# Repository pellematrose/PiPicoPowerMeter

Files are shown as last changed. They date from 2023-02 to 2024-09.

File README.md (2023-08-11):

# PiPicoPowerMeter
Check out my project site at [hackaday.io](https://hackaday.io/project/189359-pi-pico-power-meter)

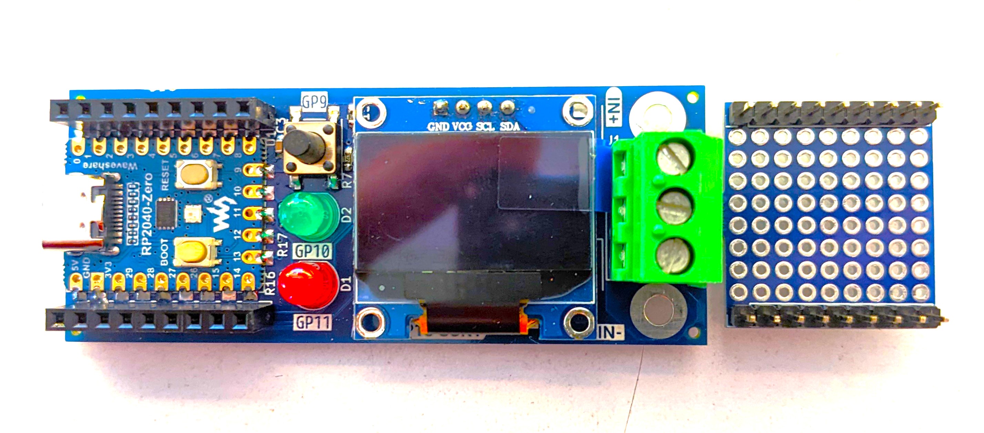
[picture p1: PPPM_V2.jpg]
PPPM_view1


Use the latest Micropython release.
Copy the content of the "RP2040 Pi Pico Code_int_log" folder to the root directory of the RP2040.

## Configuration ##
The PPPM comes pre programmed ready to go to measure up to 26V and 3.2A.

If you need other / better performance on your measured object you can change the settings in the code.
Everything is done in this function:
```python
ina.configure(SHUNT_OHMS, VBUS_RANGE_16, VSHUNT_MAX_2, BADC_12BIT, SADC_12BIT, MODE_SHUNT_BUS_C)
```
Here's how to go:
1. Estimate your maximum voltage
	1. VBUS_RANGE_32 for max. 26V
	2. VBUS_RANGE_16 for max. 16V
2. Estimate the maximum current (with 0.1Ohms shunt) and set the gain
	1. VSHUNT_MAX_1 for range +-0.04mV -> Imax = 0.4A
	2. VSHUNT_MAX_2 for range +-0.08mV -> Imax = 0.8A
	3. VSHUNT_MAX_4 for range +-0.16mV -> Imax = 1.6A
	4. VSHUNT_MAX_8 for range +-0.32mV -> Imax = 3.2A
This will change the value of the LSB and thus change the precision.
The LSB is calculated like this: $LSB = \frac{maxcurrent}{2^{15}}$
If you soldered a different shunt the max. current changes to: $I=\frac{range}{shunt}$
3. Conversion speed (the faster the less accurate) Valid for BADC (Bus voltage)and SADC (Shunt voltage)
	1. BADC_9BIT for 9bit values in 84µs
	2. BADC_10BIT for 10bit values in 148µs
	3. BADC_11BIT for 11bit values in 276µs
	4. BADC_12BIT for 12bit values in 532µs
	5. BADC_2S for 2 Samples in 1.06ms
	6. BADC_4S for 4 Samples in 2.13ms
	7. BADC_8S for 8 Samples in 4.26ms
	8. BADC_16S for 16 Samples in 8.51ms
	9. BADC_32S for 32 Samples in 17.02ms
	10. BADC_64S for 64 Samples in 34.05ms
	11. BADC_128S for 128 Samples in 68.1ms
4. Choose the mode you need
	1. MODE_POWER_DOWN compleatly off
	2. MODE_SHUNT_TRIG only shunt, triggered
	3. MODE_VOLT_TRIG  only voltage, triggered
	4. MODE_SHUNT_BUS_T shunt and voltage, triggered
	5. MODE_ADC_OFF only adc off
	6. MODE_SHUNT_C only shunt, continuous
	7. MODE_VOLT_C only voltage, continuous
	8. MODE_SHUNT_BUS_C shunt and voltage, continuous

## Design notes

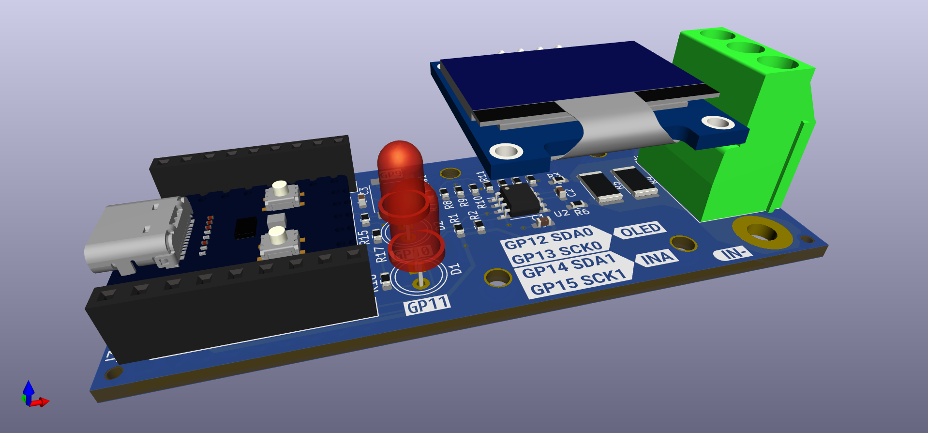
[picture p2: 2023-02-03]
PPPM_view1.png

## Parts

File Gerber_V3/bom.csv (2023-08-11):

Designator | Footprint | Quantity | Value | LCSC Part #
C1, C2 | 0603 | 2 | 100nF
C3 | 0603 | 1 | 10n
D1, D2 | LED_D5.0mm | 2 | LED
D3, D4 | D_SMB | 2 | SM6T27A
J1 | MKDS_3_3 | 1 | Conn_01x03_Female
J2, J3 | PinSocket_1x09_P2.54mm_Vertical | 2 | Conn_01x09_Female
J4, J5 | PinHeader_1x09_P2.54mm_Vertical | 2 | Conn_01x09_Female
R1, R10, R11, R12, R13, R14, R2, R7, R8, R9 | 0603 | 10 | 4k7
R15 | 0603 | 1 | 10k
R16, R17 | 0603 | 2 | 120R
R3, R6 | 0603 | 2 | 10R
R4, R5 | 2512 | 2 | 0.1R
SW1 | SW_Push_1P1T_NO_6x6mm_H9.5mm | 1 | SW_MEC_5G
U1 | RP2040-Zero_SMD | 1 | RP2040_Zero
U2 | SOIC-8_3.9x4.9mm_P1.27mm | 1 | INA219AxD
U3 | SSD1306_0.96_Oled_wo_Holes | 1 | OLED_SSD1306

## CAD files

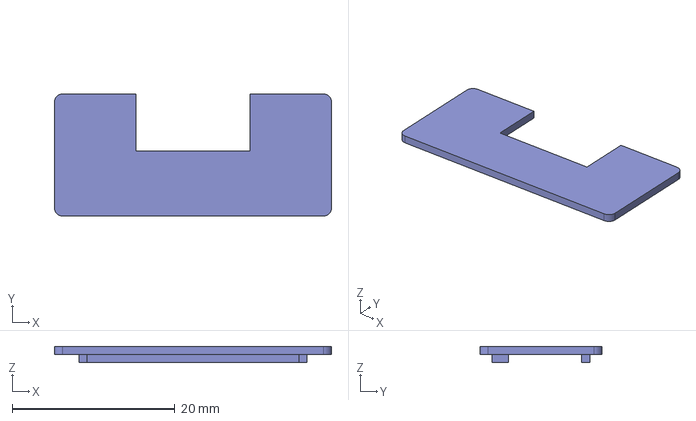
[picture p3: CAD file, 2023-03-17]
V2_Out.step
34.0 x 15.0 x 2.00 mm

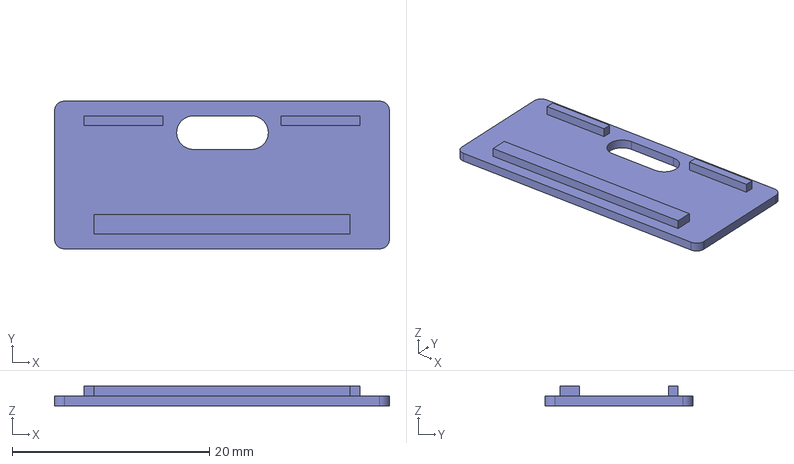
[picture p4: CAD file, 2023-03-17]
V2_USB.step
34.0 x 15.0 x 2.00 mm

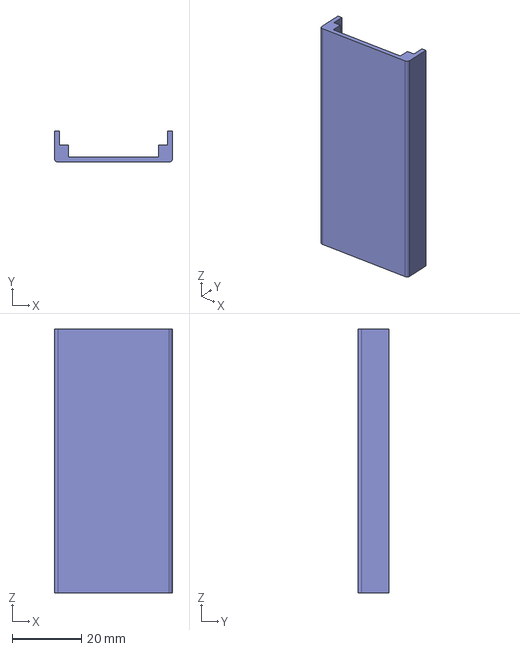
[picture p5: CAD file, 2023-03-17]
V2_Bottom.step
34.0 x 9.00 x 76.0 mm

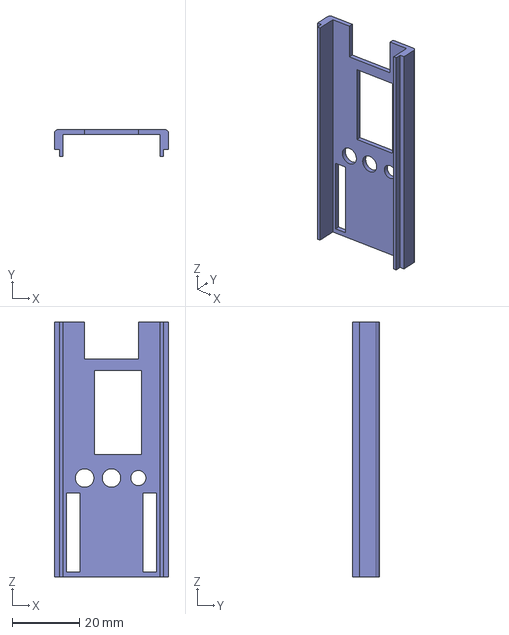
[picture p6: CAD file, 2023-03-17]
V2_Top.step
34.0 x 8.00 x 76.0 mm

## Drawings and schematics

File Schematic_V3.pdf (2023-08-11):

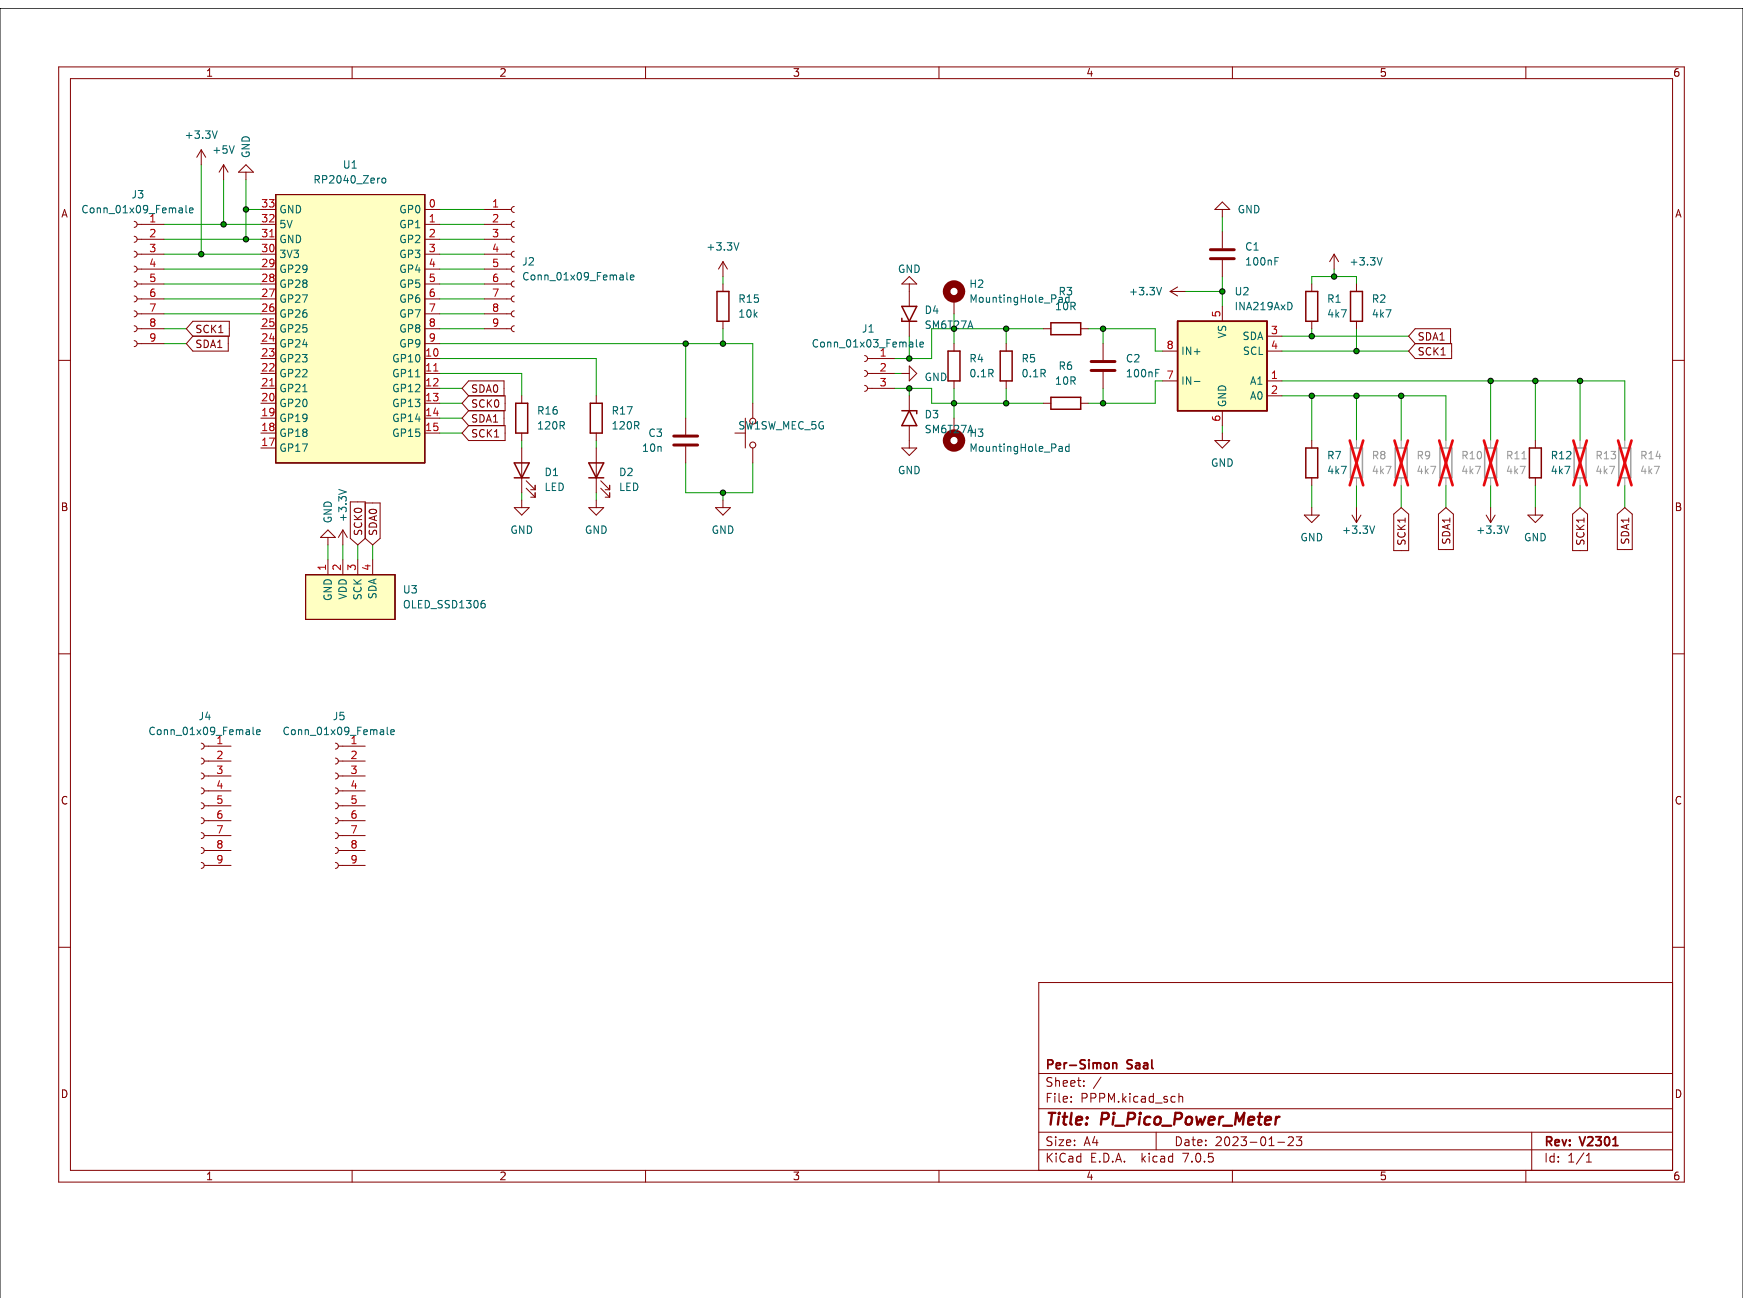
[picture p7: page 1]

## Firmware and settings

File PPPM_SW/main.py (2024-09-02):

# Inspired from
# https://www.youtube.com/watch?v=YR9v04qzJ5E
# mono_test.py Demo program for nano_gui on an SSD1306 OLED display.

# Released under the MIT License (MIT). See LICENSE.
# Copyright (c) 2018-2021 Peter Hinch

# https://learn.adafruit.com/monochrome-oled-breakouts/wiring-128x32-spi-oled-display
# https://www.proto-pic.co.uk/monochrome-128x32-oled-graphic-display.html

# V0.33 16th Jan 2021 Hardware configuration is now defined in color_setup to be
# consistent with other displays.
# V0.32 5th Nov 2020 Replace uos.urandom for minimal ports

# Last edit: 29.08.2024
# Copyright (c) 2023 Per-Simon Saal

from machine import Pin, I2C, UART
from struct import unpack
from time import sleep
import time
import math
from drivers.ina219 import ina219
import utime
from functions import format_number, show_value, multi_show_values, start_screen

from color_setup import ssd

#INA219 CONFIG
INA_ADDR = 64

VBUS_RANGE_16 = 0x00	#BRNG
VBUS_RANGE_32 = 0x01
VSHUNT_MAX_1 = 0x00		#0.040 gain
VSHUNT_MAX_2 = 0x01		#0.080
VSHUNT_MAX_4 = 0x02		#0.160
VSHUNT_MAX_8 = 0x03		#0.320

BADC_9BIT  = 0x00
BADC_10BIT = 0x01
BADC_11BIT = 0x02
BADC_12BIT = 0x03
BADC_2S = 0x08
BADC_4S = 0x0A
BADC_8S = 0x0B
BADC_16S = 0x0C
BADC_32S = 0x0D
BADC_64S = 0x0E
BADC_128S = 0x0F

SADC_9BIT  = 0x00
SADC_10BIT = 0x01
SADC_11BIT = 0x02
SADC_12BIT = 0x03
SADC_2S = 0x08
SADC_4S = 0x0A
SADC_8S = 0x0B
SADC_16S = 0x0C
SADC_32S = 0x0D
SADC_64S = 0x0E
SADC_128S = 0x0F

MODE_POWER_DOWN  = 0x00
MODE_SHUNT_TRIG  = 0x01
MODE_VOLT_TRIG   = 0x02
MODE_SHUNT_BUS_T = 0x03
MODE_ADC_OFF     = 0x04
MODE_SHUNT_C     = 0x05
MODE_VOLT_C      = 0x06
MODE_SHUNT_BUS_C = 0x07	#Shunt and bus, continuous

# actual used mode (edit here)
SHUNT_OHMS = 0.1 #R
VBUS = VBUS_RANGE_32
VSHUNT = VSHUNT_MAX_8
BADC = BADC_12BIT
SADC = SADC_12BIT
MODE = MODE_SHUNT_BUS_C

mWh = 0

# helper variables to run the code periodically
actual_time_oled = 0 
actual_time_meas = 0 
actual_time_csv = 0
last_time_oled = 0
last_time_meas = 0
last_time_csv = 0
toggle_time = 0

# refresh rate of take and show measurements in ms. EDIT here:
refresh_rate_oled = 250
refresh_rate_meas = 250
refresh_rate_csv = 500

# page of the UI
page = 0

# initialize i2c (which i2cx, GPNr., GPNr., frequency Hz)
i2c_ina  = I2C(1, scl = Pin(15), sda = Pin(14), freq = 400000)

# initialize UART on port 1 pins 4 & 5
uart1 = UART(1, baudrate=115200, tx=Pin(4), rx=Pin(5), bits=8, parity=None, stop=1)

# initialize button
button = Pin(9, Pin.IN, Pin.PULL_UP)
btn_debounce_t = 0
btn_isr_flag = 0

button2 = Pin(8, Pin.IN, Pin.PULL_UP)
btn_isr_flag2 = 0

button3 = Pin(1, Pin.IN, Pin.PULL_UP)
btn_isr_flag3 = 0

# for logging
file_name = "Logging.csv"

# initialize led1 and led2
led1 = Pin(10, Pin.OUT, None)
led1.value(0)
led2 = Pin(11, Pin.OUT, None)
led2.value(0)

# Create current measuring object
ina = ina219(INA_ADDR, i2c_ina)
ina.configure(SHUNT_OHMS, VBUS, VSHUNT, BADC, SADC, MODE)
    
# Write start screen on OLED
start_screen(VBUS, VSHUNT)

def btn_callback(button):
    global btn_isr_flag, btn_debounce_t
    if (time.ticks_ms()-btn_debounce_t) > 200:
        btn_isr_flag= 1
        btn_debounce_t=time.ticks_ms()
        
button.irq(trigger=button.IRQ_FALLING, handler=btn_callback)
   
def btn2_callback(button2):
    global btn_isr_flag2, btn_debounce_t
    if (time.ticks_ms()-btn_debounce_t) > 200:
        btn_isr_flag2= 1
        btn_debounce_t=time.ticks_ms()
        
button2.irq(trigger=button.IRQ_FALLING, handler=btn2_callback)

def btn3_callback(button3):
    global btn_isr_flag3, btn_debounce_t
    if (time.ticks_ms()-btn_debounce_t) > 200:
        if btn_isr_flag3 == 0:
            btn_isr_flag3 = 1
        else:
            btn_isr_flag3 = 0           
        #btn_isr_flag3 = 1
        btn_debounce_t=time.ticks_ms()
        led2.toggle()
        
button3.irq(trigger=button.IRQ_FALLING, handler=btn3_callback)
    
while True:
    # get system tick
    actual_time_meas = time.ticks_ms()
    actual_time_oled = time.ticks_ms()
    actual_time_csv = time.ticks_ms()
        
    # take and show measurements 'refresh_rate' seconds
    if actual_time_meas - last_time_meas > refresh_rate_meas:
        last_time_meas = actual_time_meas
    
        v = ina.vbus()
        #c = ina.vshunt()
        i = ina.current()
        p = ina.power()
        #experimental
        mWh = mWh + p / 3600
        
        #print("v = %.6fV" % v ,", i = %.6fA" % i, " P = %.6fW" % p, " E = %.6fmWh" % mWh)
        #print("%.3f"%v,",%.3f"%i,",%.2f"%p,"\n")
        
        # Output for Serial Studio
        #print('/*' + str(v) + ',' + str(i) + ',' + str(p) + '*/\n')
     
    if actual_time_oled - last_time_oled > refresh_rate_oled:
        last_time_oled = actual_time_oled
         
        if page == 0:               
            show_value("Voltage", v)
        elif page == 1:             
            show_value("Current", i)
        elif page == 2:      
            show_value("Power", p)
#         elif page == 3:    
#             show_value("Engergy", mWh)
        elif page == 3:             
            multi_show_values(v, i, p)
        
    if actual_time_csv - last_time_csv > refresh_rate_csv:
        last_time_csv = actual_time_csv                                                      
         
        if btn_isr_flag3 is 1:
            btn_isr_flag3 = 0                      
            #logging u, i and p to a csv
            with open (file_name,"a") as logging:
                logging.write(f'{str(v)}')
                logging.write(",")
                logging.write(f'{str(i)}')
                logging.write(",")
                logging.write(f'{str(p)}{"\n"}')
                logging.flush()
            logging.close()
                                  
    # todo when button is pressed
    if btn_isr_flag is 1:
        btn_isr_flag = 0
        
        if page < 3:
            page += 1
            ssd.fill(0)	# clear display when open new page
        elif page == 3:
            page = 0
            ssd.fill(0)    
    
    if btn_isr_flag2 is 1:
        btn_isr_flag2 = 0
        if page > 0:
            page -= 1
            ssd.fill(0)
        elif page == 0:
            page = 3
            ssd.fill(0)                     

    # just toggle the led1
    if actual_time_oled - toggle_time > 1000:
        toggle_time = time.ticks_ms()
        led1.toggle()

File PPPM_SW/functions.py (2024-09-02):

from color_setup import ssd                                                              
from gui.core.writer import Writer
from gui.core.nanogui import refresh                             
from gui.widgets.label import Label
from time import sleep
import time
# Fonts
import gui.fonts.arial10 as arial10
#import gui.fonts.courier20 as fixed
import gui.fonts.font6 as small
import gui.fonts.arial35 as arial35
#import gui.fonts.arial_50 as arial50
import gui.fonts.freesans20 as free20

def start_screen(bus, shunt):
    print(bus)
    print(shunt)
    if bus == 0:
        vol = 16
    elif bus == 1:
        vol = 32
    
    if shunt == 0:
        vsh = 40
    elif shunt == 1:
        vsh = 80
    elif shunt == 2:
        vsh = 160
    elif shunt == 3:
        vsh = 320
    else: vsh = 0    
    
    ssd.fill(0)
    refresh(ssd)
    
    wri = Writer(ssd, free20, verbose=False)
    wri.set_clip(False, False, False)
    Label(wri, 0, 0, 'Settings', bdcolor=False)

    wri2 = Writer(ssd, arial10, verbose=False)
    wri2.set_clip(False, False, False)
    Label(wri2, 25, 0, f"Max Volage = {vol}V")
    Label(wri2, 35, 0, f"Max Current = {vsh}mA")
    
    refresh(ssd)
    time.sleep_ms(1000)
    ssd.fill(0)
    refresh(ssd)

def format_number(num):
    if num >= 100:
        return f"{int(num)}"
    elif num >= 10:
        return f"{num:.1f}"
    elif num >= 1:
        return f"{num:.2f}"
    
def show_value(label, wert):

    if (wert < 40 and wert >= 1):
        d = "x"
        if label == "Voltage":
            d = "V"
        elif label == "Current":
            d = "A"
        elif label == "Power":
            d = "W"   
        w = f"{format_number(wert)}{d}"

    elif (wert < 1 and wert >= 0.001):
        wert = wert*1000
        d = "m"
        if label == "Voltage":
            d = "mV"
        elif label == "Current":
            d = "mA"
        elif label == "Power":
            d = "m"
        w = f"{format_number(wert)}{d}"

    else:
        wert = wert*1000000
        d = "u"
        w = f"{format_number(wert)}{d}"
    
    wri = Writer(ssd, free20, verbose=False)
    wri.set_clip(False, False, False)
    Label(wri, 0, 2, label)
    
    wri2 = Writer(ssd, arial35, verbose=False)
    wri2.set_clip(False, False, False)
    Label(wri2, 27, 0, '            ', bdcolor=False)
    Label(wri2, 27, 0, w, bdcolor=False)

    refresh(ssd)
    
def multi_show_values(voltage, current, power):
    u = f"{voltage:.3f}{"V"}"
    i = f"{current:.3f}{"A"}"
    p = f"{power:.3f}{"W"}"
                                                                     
    wri = Writer(ssd, free20, verbose=False)
    wri.set_clip(False, False, False)
    Label(wri, 2, 2, 'Overview', bdcolor=False)

    Writer.set_textpos(ssd, 20, 0)  # In case previous tests have altered it
    wri = Writer(ssd, small, verbose=False)
    wri.set_clip(False, False, False)

    Label(wri, 23, 2, 'U:', bdcolor=False)                                                               
    Label(wri, 23, 15, '                    ', bdcolor=False) # draw black space to erase former value
    Label(wri, 23, 15, u, bdcolor=False)

    Label(wri, 36, 2, 'I:', bdcolor=False)                                                                  
    Label(wri, 36, 15, '                    ', bdcolor=False) # draw black space to erase former value
    Label(wri, 36, 15, i, bdcolor=False)
    
    Label(wri, 49, 2, 'P:', bdcolor=False)                                                                  
    Label(wri, 49, 15, '                    ', bdcolor=False) # draw black space to erase former value
    Label(wri, 49, 15, p, bdcolor=False)    
    
    refresh(ssd)    

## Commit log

2023-08-11 Data V3
    [bom.csv, designators.csv, positions.csv]
2023-08-11 Add Schematic pdf
2024-08-28 Update main.py
    code cleanup, support for mili volts, amps, watts
2024-08-29 Update main.py
    Added two more buttons, different sample times for oled, measurement and csv, code cleanup
